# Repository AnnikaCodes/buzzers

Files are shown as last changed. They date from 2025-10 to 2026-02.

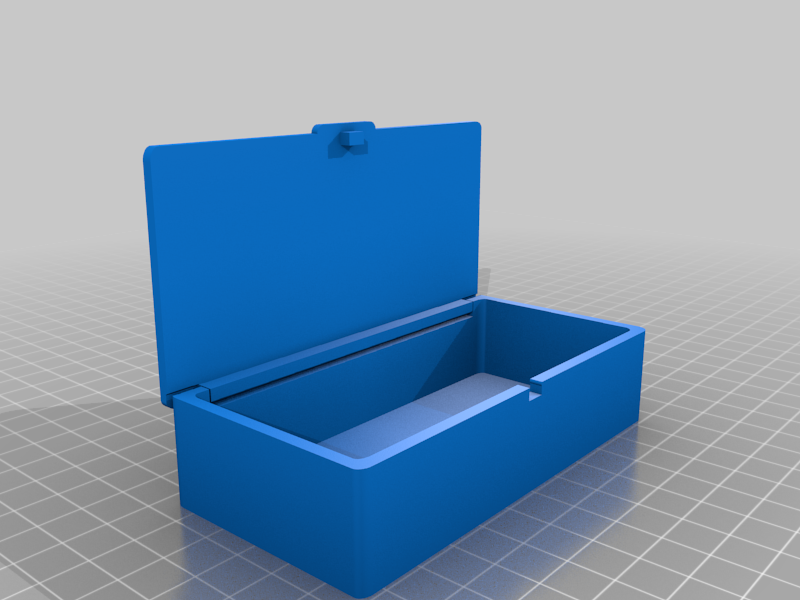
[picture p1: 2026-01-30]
Hinge box with a premounted lid (Print at once) - 1155457/images/e5d918d74d63d429b114cd56e46e2572.png

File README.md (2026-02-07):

# ABACUS: Annika's Buzzers for Ascertaining Competitive Unique Signals
a lower-cost buzzer system for quizbowl competitions

the 3D models were based on https://www.thingiverse.com/thing:12686 and https://www.thingiverse.com/thing:1432052 and https://www.thingiverse.com/thing:1155457

check out [the 'real' website for these!](https://worldbrightening.net/buzzers/)

I don't yet have detailed directions for building it, but you should definitely:
- get a PCB; you can fabricate [these files](https://github.com/AnnikaCodes/buzzers/tree/main/buzzer-pcb), or I'll send you one (almost certainly for cheaper and potentially for free) if you [contact me](mailto:annika@worldbrightening.net)
- buy [stuff from DigiKey](https://www.digikey.com/en/mylists/list/PRWZMR6ARL) (I don't know if this list is complete... you also will definitely need a [speaker](https://www.amazon.com/MakerHawk-Full-Range-Advertising-Connector-Separating/dp/B07GJ4GH67) and some resistors and please, like, [email me about this](mailto:annika@worldbrightening.net) or Discord me or something if you are going to build this! I will help you!)
- print 10 of the [3D models for the buzzers](https://github.com/AnnikaCodes/buzzers/blob/main/3Dmodels/buzzer2.stl) and one of the [3D models for the case](https://github.com/AnnikaCodes/buzzers/blob/main/buzzer-case.stl) (which I still need to move the hole for the cord down to make it actually fit....)
- cut in half your 4p4c cables, push the wire ends through, solder the pushbutton switch to the right wires (this should be RED and GREEN but maybe double check with a multimeter?) and the LED positive lead to black and ground lead to yellow. 
    - be sure to use electrical tape or heatshrink to make it not short itself out!
- glue the buzzers together, and maybe put some superglue around the bottom to stop people from yanking the cord out
- solder all the jacks to the PCB and resistors to limit the current to the LEDs to the board --- whatever you need to reduce 3.3V to a reasonable amount of current given the diode drop of the LED you're using, but I used 50-60 Ohms and mine haven't broken yet.
- solder the Raspberry Pi to the board, maybe with headers if desired
- put red + green LEDs and a switch into the case with wires attached, then attach the wires either directly to the board with solder in the appropriate places, or through headers
- glue the switch into the case, and close the case
- download the software and you're off!

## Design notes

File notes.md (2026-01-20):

# Notes on constructing ABACUS
- Cable scheme: Black - GND (for LED), Red - +3.3V for switch, Green: +2.whateverV for LED, Yellow: switch.
## Notes from the Pi Pico manual
- "If the USB port is the only power source, VSYS and VBUS can be safely shorted together to eliminate the Schottky diode
drop (which improves efficiency and reduces ripple on VSYS)."
   - seems like we should power from USB and short these together
   - could also consider adding batteries, but why?
- Maybe we can use interrupts rather than an active loop --- pg. 16 of https://datasheets.raspberrypi.com/pico/raspberry-pi-pico-python-sdk.pdf --- but I worry about speed.
- I don't think that multicore should help for this project?
- It seems like we can't control USB from MicroPython directly, so we might need to use the REPL for computer-control? Or I2C/SPI/etc?
    - maybe i'm wrong: https://kyuubi0323.github.io/posts/MCU-Pico2/, https://stackoverflow.com/questions/74390514/serial-communication-between-raspberry-pi-pico-and-pc, https://learnembeddedsystems.co.uk/pico-usb-serial-code
    - need to read these ^^^`
- Should probably put resistors before the LEDs, so that voltage across LED is not too high. Want voltage across to be 2.1V at <= 20mA. Say we provide 3.3V initially. Diode drop is ~2.1 V (up to 2.8V), so V drop across resistor is 3.3V - 2.1 V = 1.2V (or at minimum 0.5V). R = V/I = 1.2V/(20 mA) = 60 ohm, so let's try a 60 ohm resistor. 50 ohm would give

- TODO: fix bug where simulatenous buzzes

Buzzer wired 11/8: Green jack wire -> LED +, Red jack wire -> LED -, black & yellow => switch

1/17: to convert proto buzzer -> new buzzer add an extra wire and wire the following in the cable together:
- black->green
- yellow->red
- green->black
- red->yellow

(the PCB jacks send red->input pin, yellow->ground, black->LED resistor, green->3v3

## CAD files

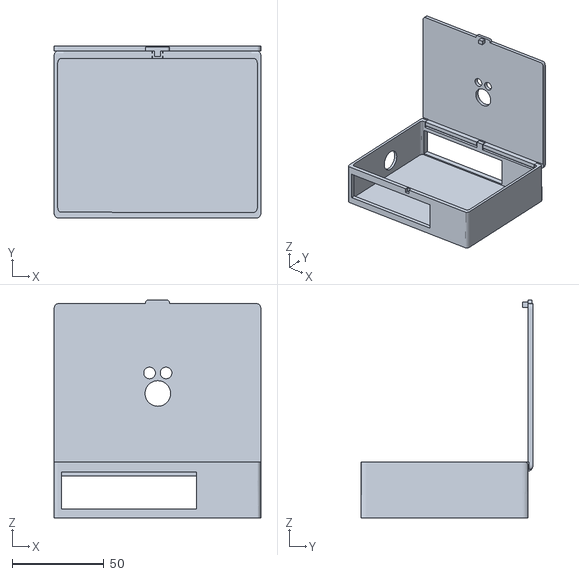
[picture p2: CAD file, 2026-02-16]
3Dmodels/buzzer-case.stl
113.0 x 93.8 x 119.0

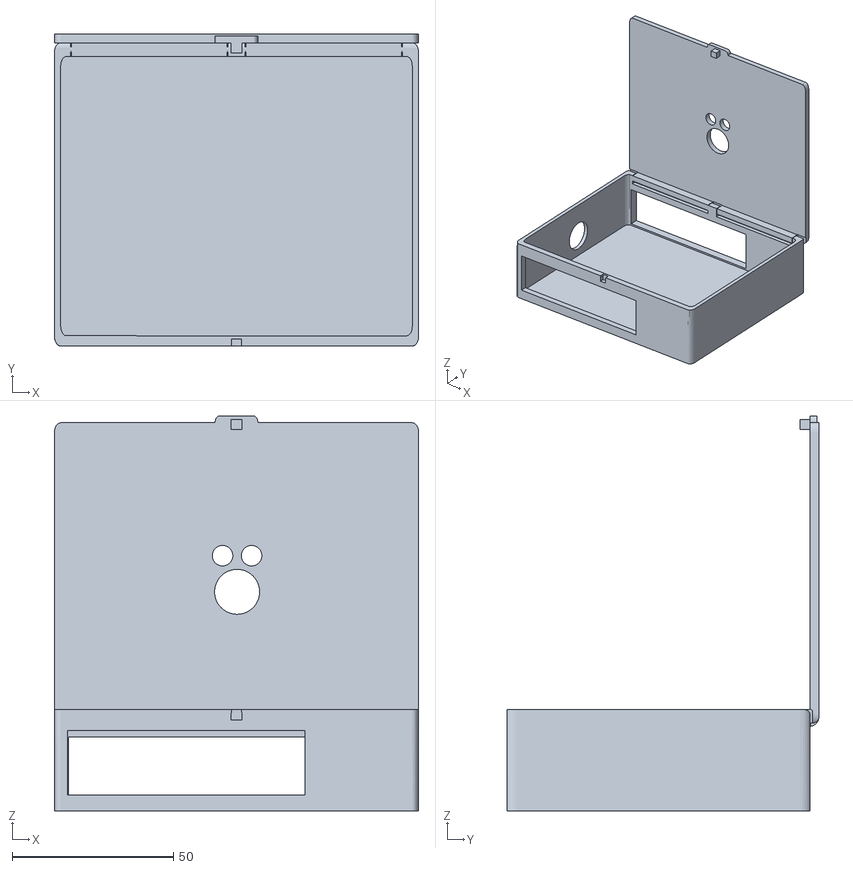
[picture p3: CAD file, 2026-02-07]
buzzer-case.bad.stl
113.0 x 96.8 x 122.5

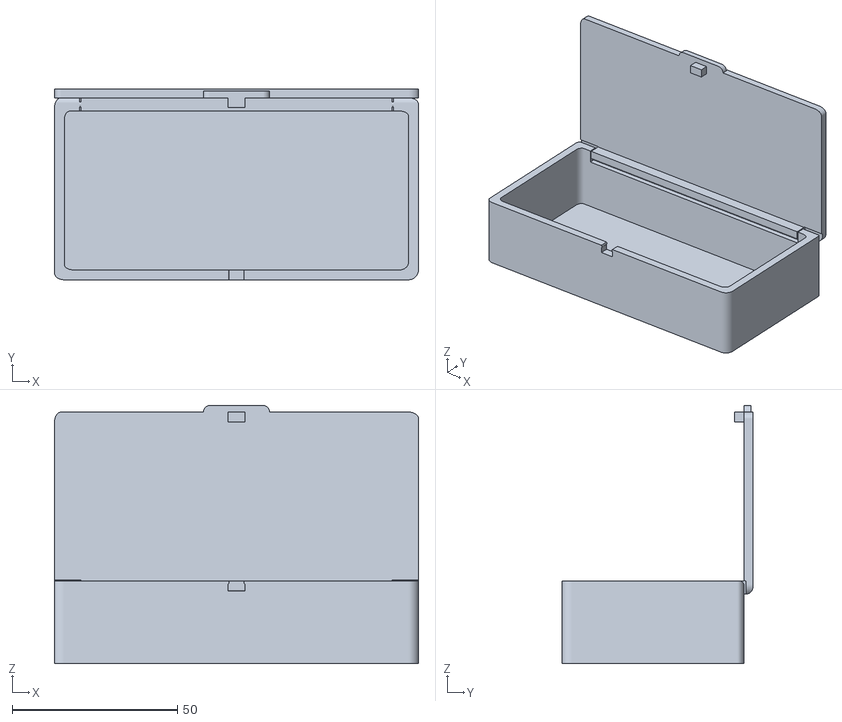
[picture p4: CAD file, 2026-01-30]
Hinge box with a premounted lid (Print at once) - 1155457/files/Hinge_Box-55-110-25.stl
110.0 x 57.6 x 78.0

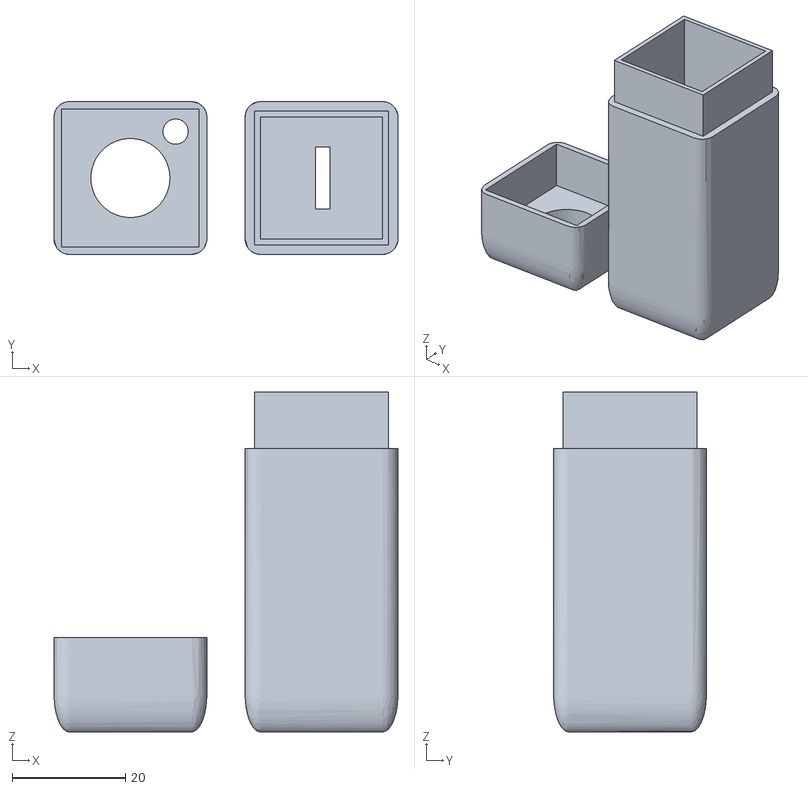
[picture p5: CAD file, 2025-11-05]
3Dmodels/buzzerwiderLEDhole.stl
60.8 x 27.0 x 60.0

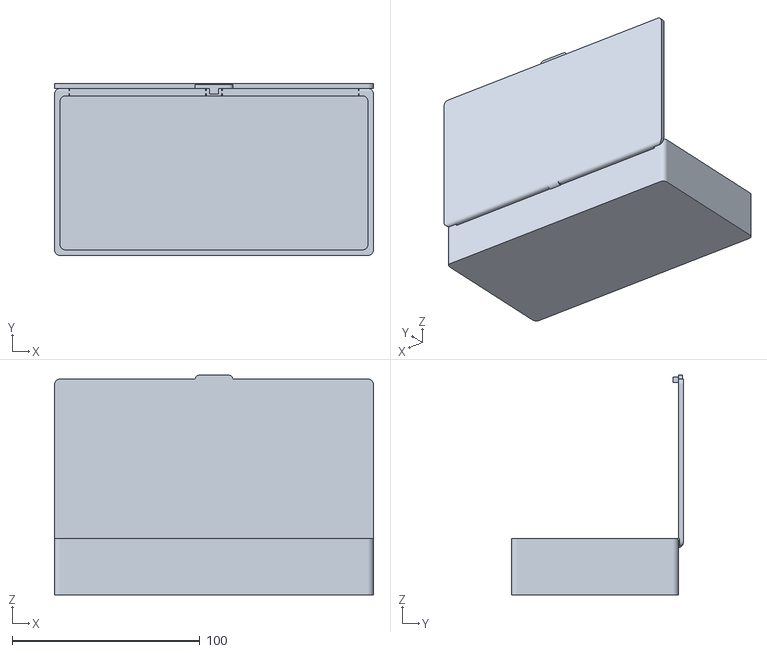
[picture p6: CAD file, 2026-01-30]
Hinge box with a premounted lid (Print at once) - 1155457/files/Hinge_Box-89-170-30.stl
170.0 x 91.6 x 117.0

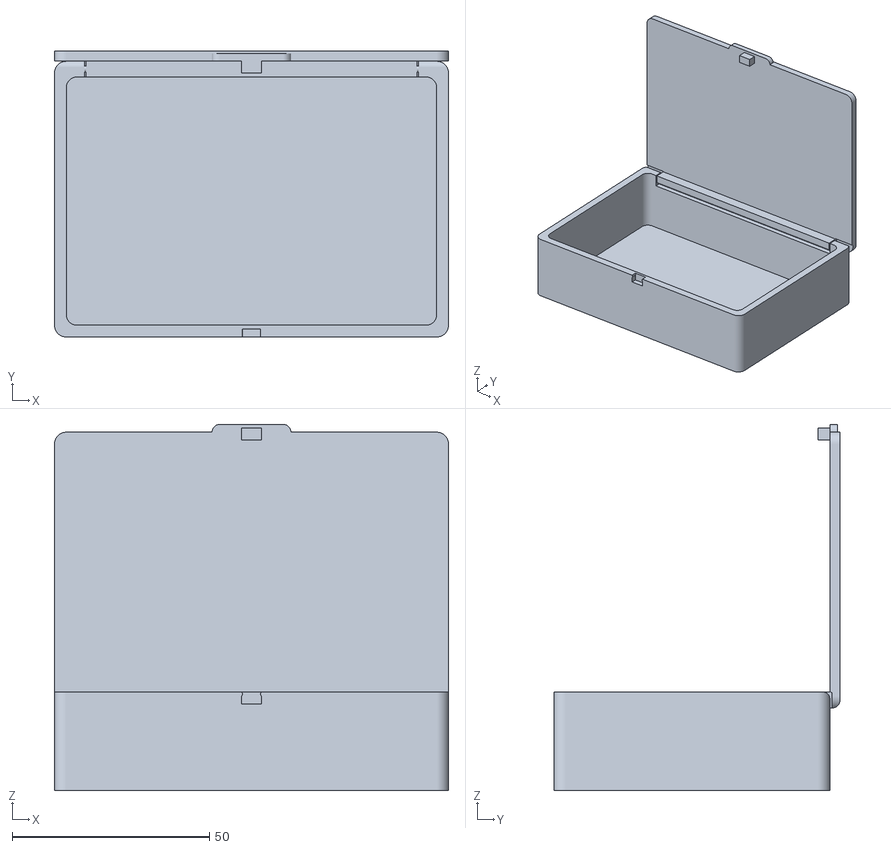
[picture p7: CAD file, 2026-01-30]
Hinge box with a premounted lid (Print at once) - 1155457/files/Hinge_Box-70-100-25.stl
100.0 x 72.6 x 93.0

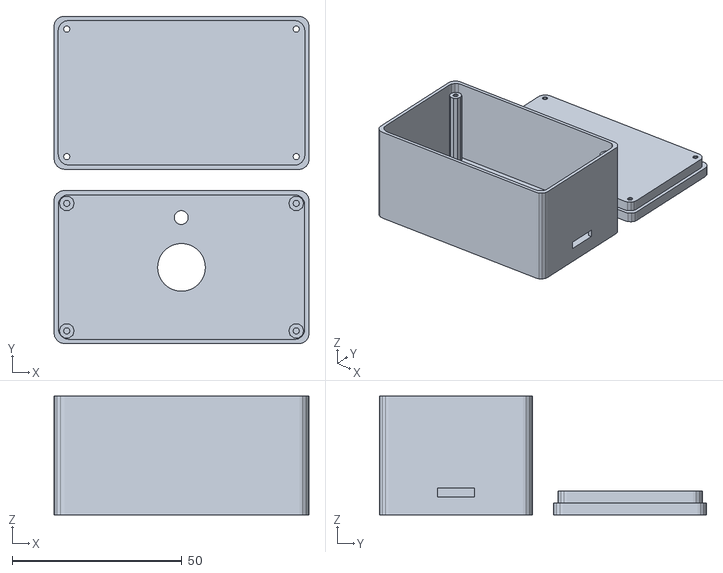
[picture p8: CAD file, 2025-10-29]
3Dmodels/rectangular-buzzer.stl
75.0 x 96.3 x 35.0

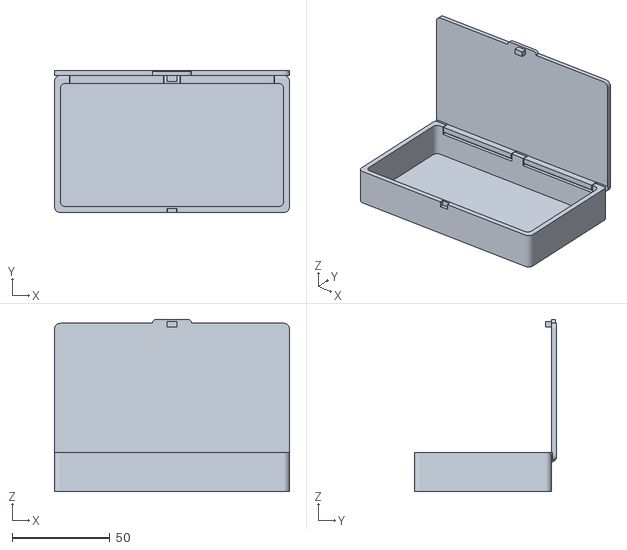
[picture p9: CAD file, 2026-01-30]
Hinge box with a premounted lid (Print at once) - 1155457/files/Hinge_Box-70-120-20.stl
120.0 x 72.6 x 88.0

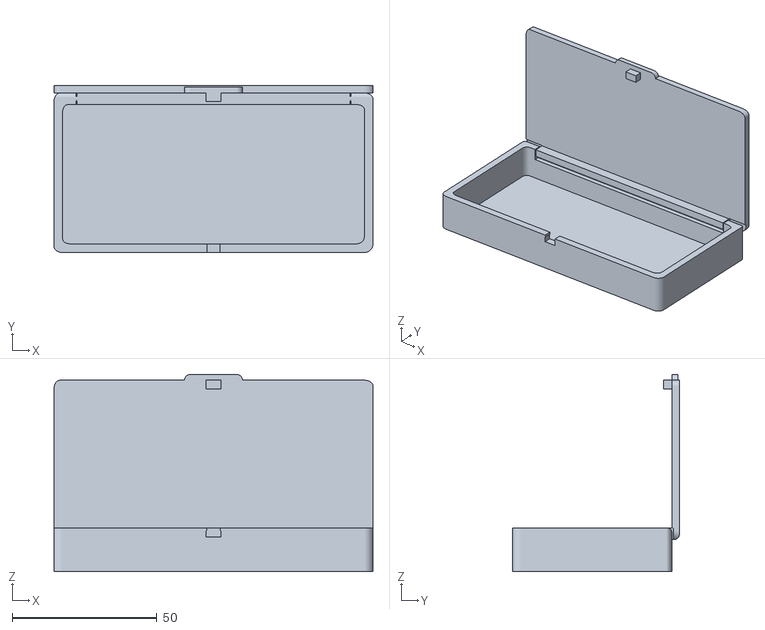
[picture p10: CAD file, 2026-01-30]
Hinge box with a premounted lid (Print at once) - 1155457/files/Hinge_Box-55-110-15.stl
110.0 x 57.6 x 68.0

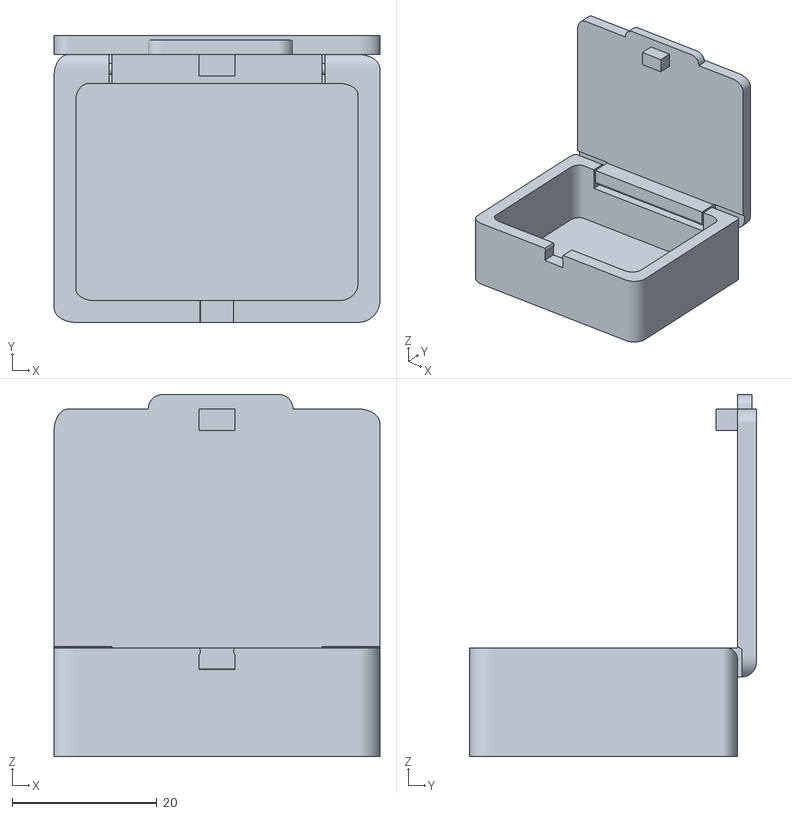
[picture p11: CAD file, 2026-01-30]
Hinge box with a premounted lid (Print at once) - 1155457/files/Hinge_Box-37-45-15.stl
45.0 x 39.6 x 50.0

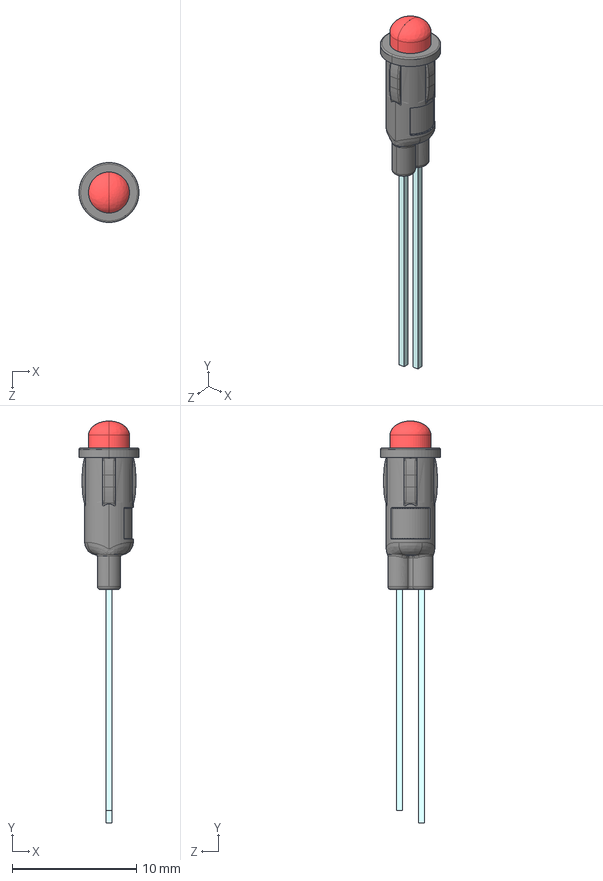
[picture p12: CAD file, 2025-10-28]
3Dmodels/digikey/PM3XXX.igs
4.83 x 32.4 x 4.83 mm

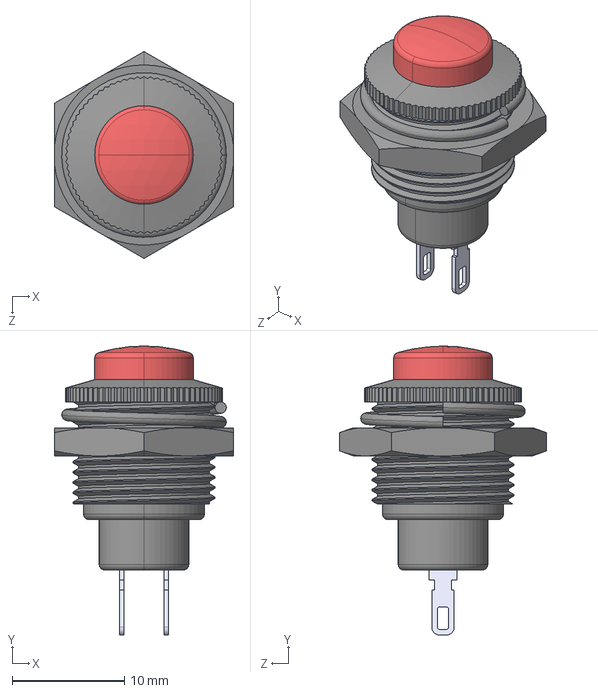
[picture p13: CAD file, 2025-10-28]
3Dmodels/digikey/RP3502ARED.STEP
16.0 x 25.8 x 18.5 mm

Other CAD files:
3Dmodels/buzzer2.stl

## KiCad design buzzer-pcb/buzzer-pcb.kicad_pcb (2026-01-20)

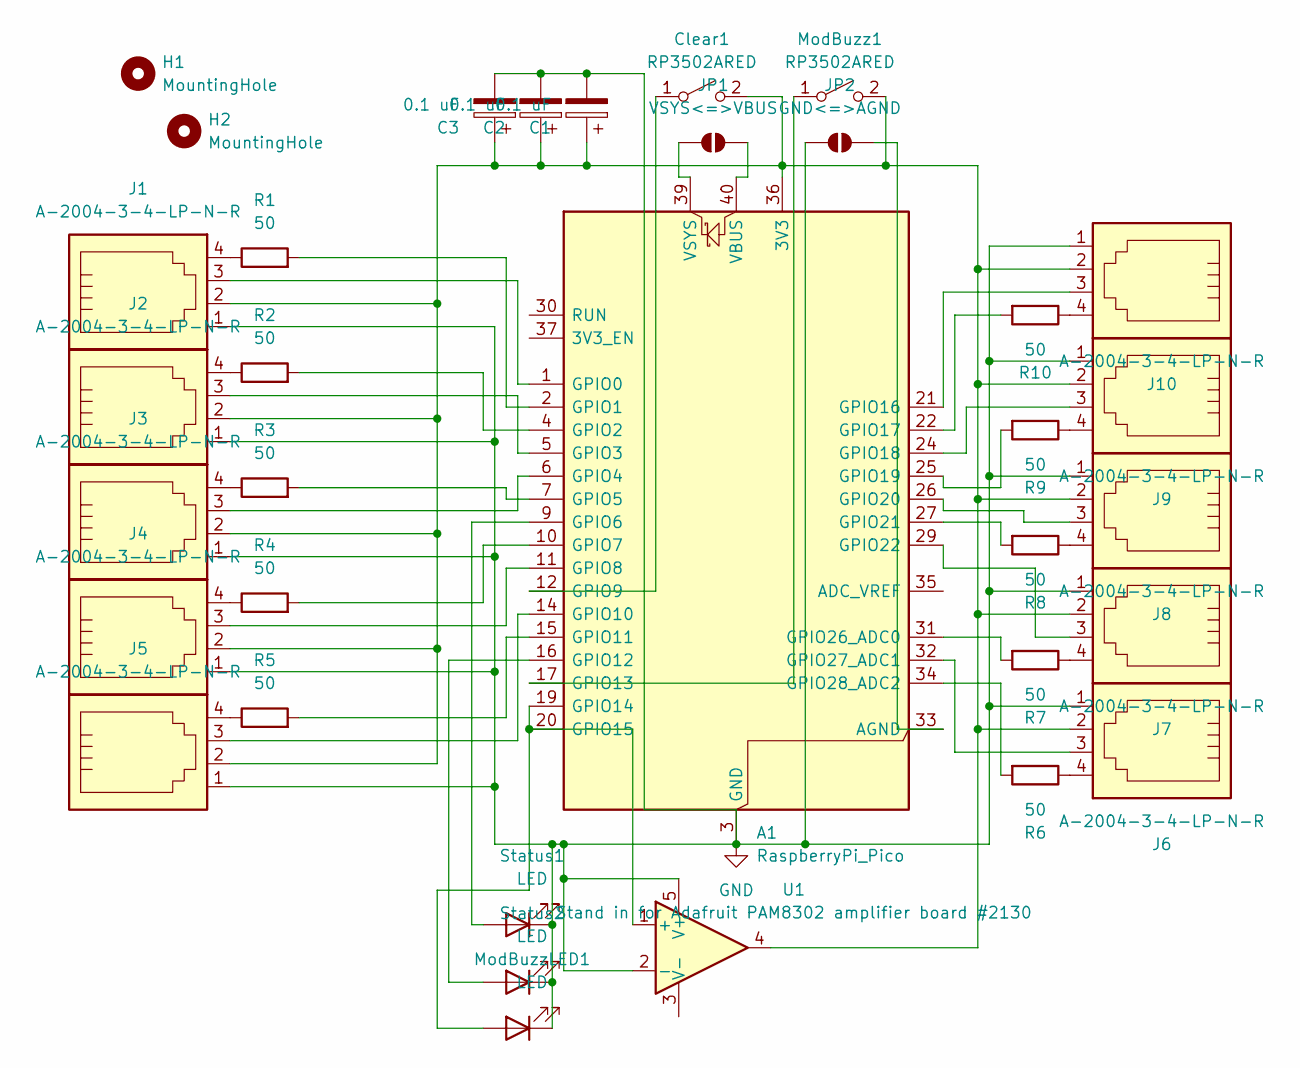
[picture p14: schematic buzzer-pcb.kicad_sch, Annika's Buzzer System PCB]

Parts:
A1: RaspberryPi_Pico; RaspberryPi_Pico_Common_THT
C1, C2, C3: 0.1 uF; XTAL_ZTA-2.44MG
Clear1: RP3502ARED; SW_CW_GPTS203211B
H1, H2: MountingHole; MountingHole_3.2mm_M3
J1, J2, J3, J4, J5, J6, J7, J8, J9, J10: A-2004-3-4-LP-N-R; Jack for Buzzers
JP1: VSYS<=>VBUS; SolderJumper-2_P1.3mm_Bridged_Pad1.0x1.5mm
JP2: GND<=>AGND; SolderJumper-2_P1.3mm_Bridged_Pad1.0x1.5mm
ModBuzz1: RP3502ARED; SW_CW_GPTS203211B
ModBuzzLED1: LED; LED_D5.0mm
R1, R2, R3, R4, R5, R6, R7, R8, R9, R10: 50; R_Axial_DIN0414_L11.9mm_D4.5mm_P15.24mm_Horizontal
Status1, Status2: LED; LED_D5.0mm
U1: Stand in for Adafruit PAM8302 amplifier board #21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; TO-264-5_Horizontal_TabDown

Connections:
GND: A1.3 (GND), A1.8 (GND), A1.13 (GND), A1.18 (GND), A1.23 (GND), A1.28 (GND), A1.38 (GND), C1.2, C2.2, C3.2, J1.1, J2.1, J3.1, J4.1, J5.1, J6.1, J7.1, J8.1, J9.1, J10.1, JP2.1 (A), ModBuzzLED1.1 (K), Status1.1 (K), Status2.1 (K), U1.2 (-), U1.5 (V+)
unnamed: A1.36 (3V3), C1.1, C2.1, C3.1, Clear1.2 (B), J1.2, J2.2, J3.2, J4.2, J5.2, J6.2, J7.2, J8.2, J9.2, J10.2, ModBuzz1.2 (B), U1.4
unnamed: A1.33 (AGND), JP2.2 (B)
unnamed: A1.1 (GPIO0), J1.3
unnamed: A1.2 (GPIO1), R1.2
unnamed: A1.4 (GPIO2), R2.2
unnamed: A1.5 (GPIO3), J2.3
unnamed: A1.6 (GPIO4), J3.3
unnamed: A1.7 (GPIO5), R3.2
unnamed: A1.9 (GPIO6), Status1.2 (A)
unnamed: A1.10 (GPIO7), R4.2
unnamed: A1.11 (GPIO8), J4.3
unnamed: A1.12 (GPIO9), Clear1.1 (A)
unnamed: A1.14 (GPIO10), J5.3
unnamed: A1.15 (GPIO11), R5.2
unnamed: A1.16 (GPIO12), Status2.2 (A)
unnamed: A1.17 (GPIO13), ModBuzz1.1 (A)
unnamed: A1.19 (GPIO14), A1.20 (GPIO15), ModBuzzLED1.2 (A), U1.1 (+)
unnamed: A1.21 (GPIO16), J10.3
unnamed: A1.22 (GPIO17), R10.2
unnamed: A1.24 (GPIO18), J9.3
unnamed: A1.25 (GPIO19), R9.2
unnamed: A1.26 (GPIO20), J8.3
unnamed: A1.27 (GPIO21), R8.2
unnamed: A1.29 (GPIO22), J7.3
unnamed: A1.31 (GPIO26_ADC0), R7.2
unnamed: A1.32 (GPIO27_ADC1), J6.3
unnamed: A1.34 (GPIO28_ADC2), R6.2
unnamed: A1.40 (VBUS), JP1.2 (B)
unnamed: A1.39 (VSYS), JP1.1 (A)
unnamed: J1.4, R1.1
unnamed: J2.4, R2.1
unnamed: J3.4, R3.1
unnamed: J4.4, R4.1
unnamed: J5.4, R5.1
unnamed: J6.4, R6.1
unnamed: J7.4, R7.1
unnamed: J8.4, R8.1
unnamed: J9.4, R9.1
unnamed: J10.4, R10.1

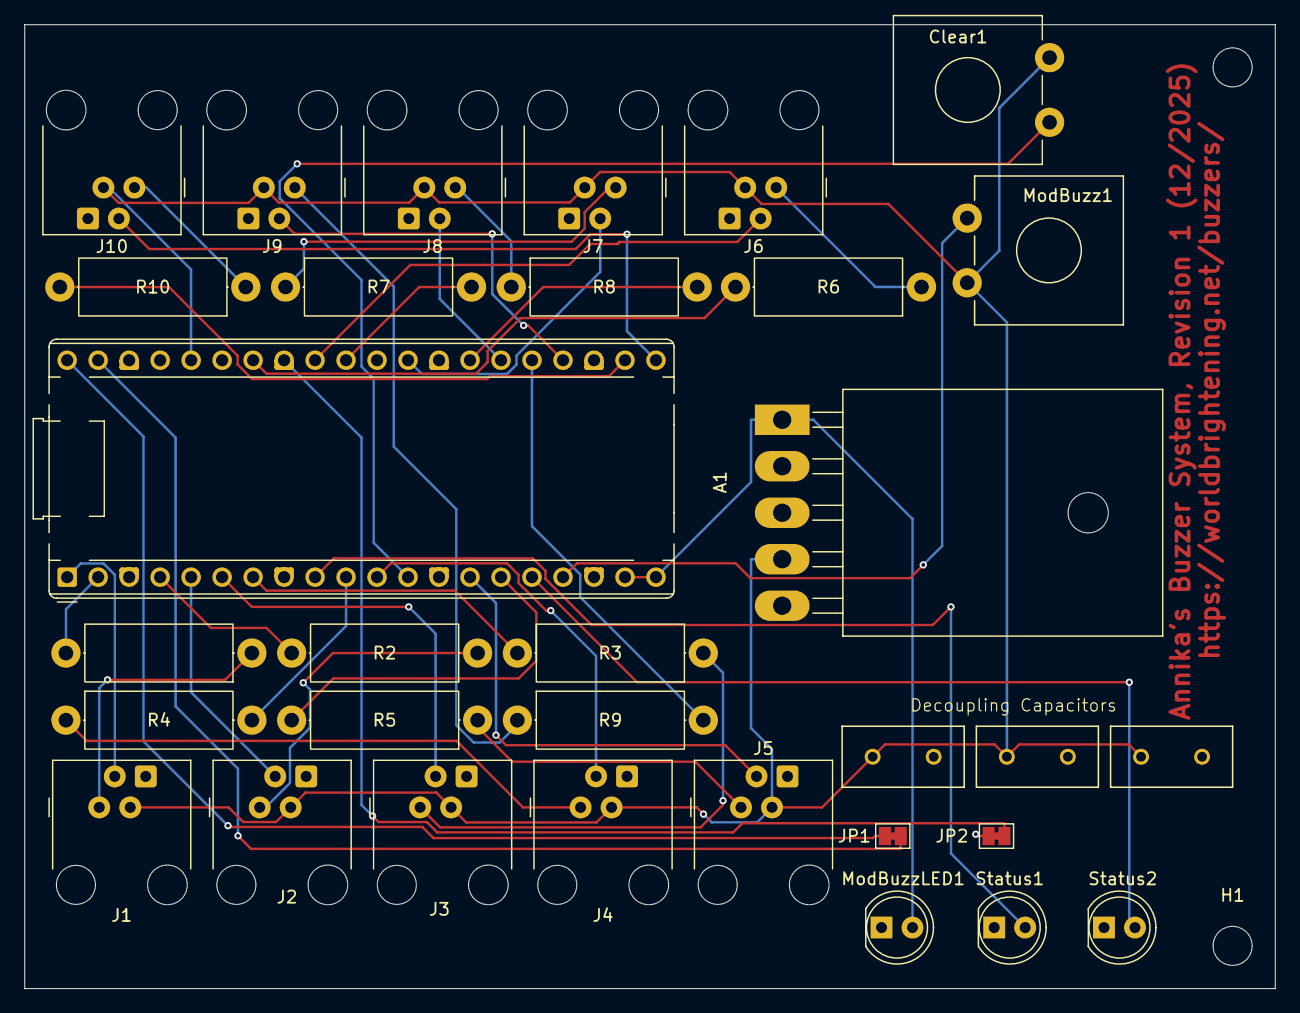
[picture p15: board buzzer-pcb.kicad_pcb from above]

Board: 2 copper layers, 102.5 x 79.0 mm, 34 parts (0 on the bottom side), 40 nets.

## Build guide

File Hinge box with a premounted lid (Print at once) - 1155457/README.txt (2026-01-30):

Hinge box with a premounted lid (Print at once) by AhmetCelikPhd on Thingiverse: https://www.thingiverse.com/thing:1155457

Summary:
Update3 70x120x20 dimension version added.  put extra support for the hinges in this version right in the middle of the lid because it is so tall.Update2 70x100x25 dimension version added.Update1 89x170x30 dimension version added. I put extra support for the hinges in this version right in the middle of the lid because it is so tall.This is a hinged box with a premounted cover.This product is a single piece and its hinge is ready to rotate. No screws, glue, magnet or nails are required.Useful for keeping small stuff like needle, button, secrew, pills or something like these.There is no need to get parts together after print. It designed as a solid piece.You can see that there is opposing covs and rims on both sides over the hinge area.The lid was separate from the box but has to be print at once. It has a opening/closing function due to pre designed hinged part.I've made it completely stable. This is why I deleted previous uploads. If required, I can upload whatever dimesnsions you need.37x45x15Outer dimensions: W: 37mm  L: 45mm  H: 15mmInner dimension: W: 31mm  L: 28mm  H: 12mm55x110x15Outer dimensions: W: 55mm  L: 110mm  H: 15mmInner dimension: W: 49mm  L: 103mm  H: 12mm55x110x25Outer dimensions: W: 55mm  L: 110mm  H: 25mmInner dimension: W: 49mm  L: 103mm  H: 22mm70x100x25Outer dimensions: W: 70mm  L: 100mm  H: 25mmInner dimension: W: 64mm  L: 94mm  H: 22mm70x120x20Outer dimensions: W: 70mm  L: 120mm  H: 20mmInner dimension: W: 64mm  L: 114mm  H: 17mm89x170x30Outer dimensions: W: 89mm  L: 170mm  H: 30mmInner dimension: W: 83mm  L: 164mm  H: 24mmPlease use support. Will not be able to print the hinge properly if you do not use support.

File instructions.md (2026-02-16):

# Detailed notes on how I built the second buzzer set for UCI
1. 3D printed two sets of five buzzers [this gcode file](https://github.com/AnnikaCodes/buzzers/blob/main/3Dmodels/five_buzzers.gcode)
2. Put the jacks ([A-2004-3-4-LP-N-R](https://www.digikey.com/en/products/detail/assmann-wsw-components/A-2004-3-4-LP-N-R/2183632) into the PCB
3. Solder male-male header pins into Raspberry Pi Pico 2.
4. Solder jacks into PCB, 56 Ohm resistor into PCB (R1-R9); R10 got a ~66 Ohm resistor because they're out.
5. For Adafruit STEMMA amp, connect VIN -> 3.3V (4th from top/2nd from bottom where rectangle is at the top), GND -> ground (2nd from the top where the top is the rectangular pin on the audio "A1"), signal -> audio pin (which I think is the rectangle at the top??? but I shall check first)

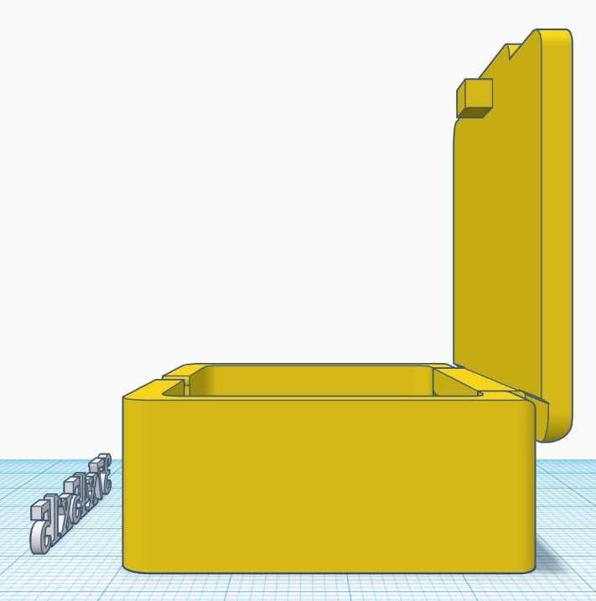
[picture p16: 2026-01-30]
Hinge box with a premounted lid (Print at once) - 1155457/images/yan.jpg

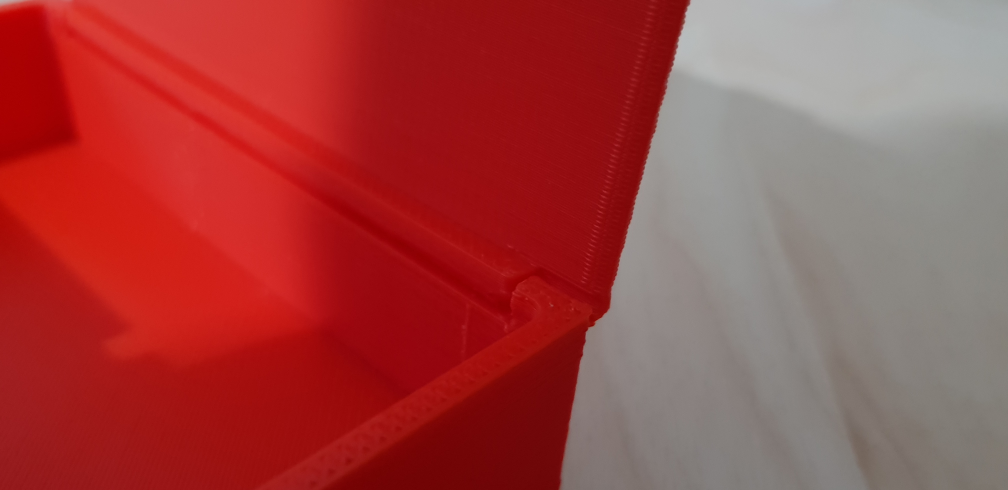
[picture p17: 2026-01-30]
Hinge box with a premounted lid (Print at once) - 1155457/images/image.png

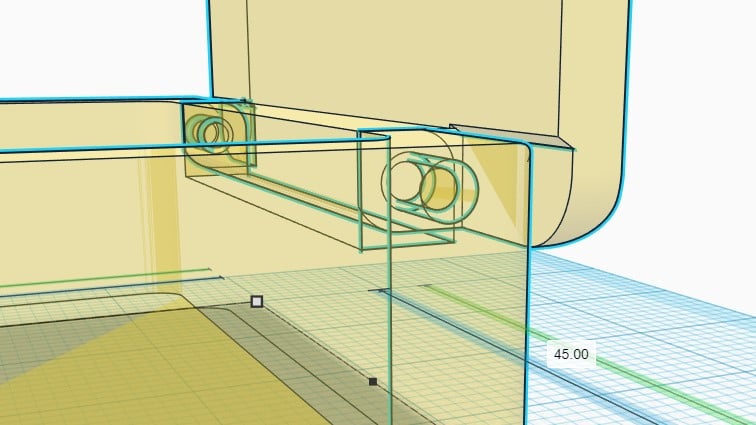
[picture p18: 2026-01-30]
Hinge box with a premounted lid (Print at once) - 1155457/images/mentese.jpg

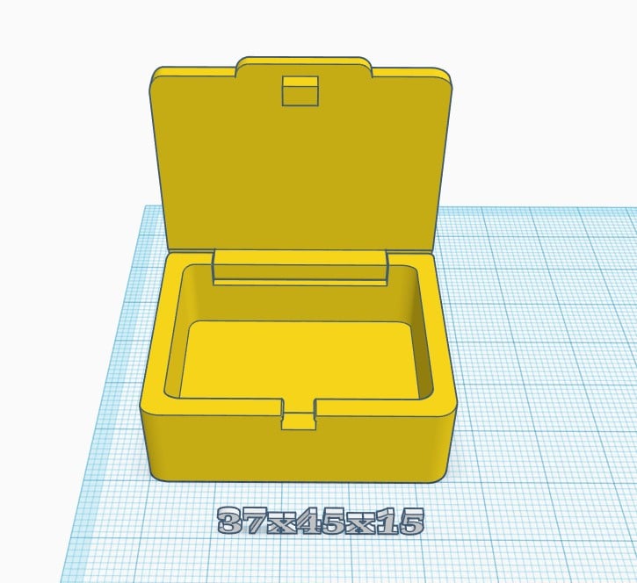
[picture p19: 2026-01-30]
Hinge box with a premounted lid (Print at once) - 1155457/images/37-45-15.jpg

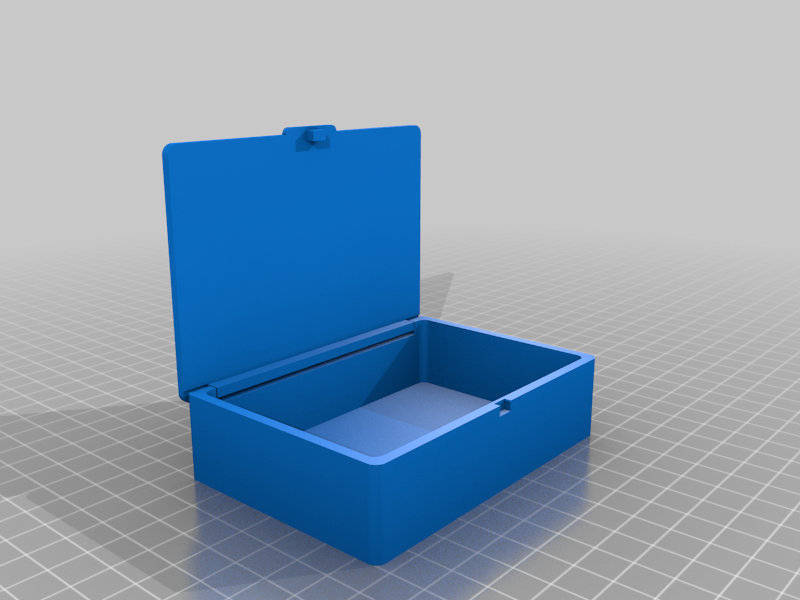
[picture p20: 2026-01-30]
Hinge box with a premounted lid (Print at once) - 1155457/images/Hinge_Box-70-100-25.png

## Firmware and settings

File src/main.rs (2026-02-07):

// Adapted from https://docs.rs/eframe/latest/eframe/
mod app;
mod serial;

fn main() {
    // let mut serial_connection = serial::try_get_serial_connection(1);

    // println!("Reading serial messages...");
    // loop {
    //     match serial::get_serial_message(&mut serial_connection) {
    //         Ok(Some(messages)) => {
    //             for message in messages {
    //                 println!("{}", message.to_human_readable());
    //             }
    //         },
    //         Ok(None) => {
    //             // No message received within timeout
    //         },
    //         Err(e) => {
    //             eprintln!("Error reading serial message: {}", e);
    //         },
    //     }
    // }

    // from https://github.com/emilk/eframe_template/blob/main/src/main.rs#L13
    let native_options = eframe::NativeOptions {
        viewport: egui::ViewportBuilder::default()
            .with_inner_size([400.0, 300.0])
            .with_min_inner_size([300.0, 220.0])
            .with_icon(
                // NOTE: Adding an icon is optional
                eframe::icon_data::from_png_bytes(
                    &include_bytes!("../openclipart-vectors-button-155539.png")[..],
                )
                .expect("Failed to load icon"),
            ),
        ..Default::default()
    };

    match eframe::run_native(
        "Annika's Buzzer System",
        native_options,
        Box::new(|cc| Ok(Box::new(app::App::new(cc)))),
    ) {
        Ok(_) => println!("GUI ran succesfully."),
        Err(e) => {
            eprintln!("Error: {}", e);
            std::process::exit(-1);
        }
    }
}

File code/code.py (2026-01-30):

import digitalio
import board
import audiomp3
import audiopwmio
import protocol

CLEAR_PIN = board.GP13
# (led, switch)
GREEN_TEAM_PINS = [(board.GP17, board.GP16), (board.GP19, board.GP18), (board.GP21, board.GP20), (board.GP26, board.GP22), (board.GP28, board.GP27)] # todo what is pin for last red team?
RED_TEAM_PINS = [(board.GP1, board.GP0), (board.GP2, board.GP3), (board.GP5, board.GP4), (board.GP7, board.GP8), (board.GP11, board.GP10)]

clear = digitalio.DigitalInOut(CLEAR_PIN)
clear.switch_to_input(pull=digitalio.Pull.DOWN)

red_led = digitalio.DigitalInOut(board.GP6)
red_led.switch_to_output(value=False)

green_led = digitalio.DigitalInOut(board.GP12)
green_led.switch_to_output(value=False)

# led, switch, buzz_protocol, lockout_protocol
red_pins = []
green_pins = []
for i in range(len(RED_TEAM_PINS)):
    red_pins.append((
        digitalio.DigitalInOut(RED_TEAM_PINS[i][0]),
        digitalio.DigitalInOut(RED_TEAM_PINS[i][1]),
        protocol.RED_TEAM_BUZZES[i],
        protocol.RED_TEAM_LOCKOUTS[i]
    ))
for i in range(len(GREEN_TEAM_PINS)):
    green_pins.append((
        digitalio.DigitalInOut(GREEN_TEAM_PINS[i][0]),
        digitalio.DigitalInOut(GREEN_TEAM_PINS[i][1]),
        protocol.GREEN_TEAM_BUZZES[i],
        protocol.GREEN_TEAM_LOCKOUTS[i]
    ))
# print(red_pins)

for led, switch, _, _ in red_pins + green_pins:
    led.switch_to_output(value=False)
    led.direction = digitalio.Direction.OUTPUT
    switch.switch_to_input(pull=digitalio.Pull.DOWN)
    led.value = True

import time
red_led.value = True
green_led.value = True
audio = audiopwmio.PWMAudioOut(board.GP14)

def play_startup():
    b = audiomp3.MP3Decoder(open("./startup.mp3", "rb"))
    audio.play(b)
play_startup()
while audio.playing:
    pass
time.sleep(1)

for led, _, _, _ in red_pins + green_pins:
    led.value = False
red_led.value = False
green_led.value = False


# https://learn.adafruit.com/mp3-playback-rp2040/pico-mp3
import supervisor
import sys
def check_for_serial_message():
    if supervisor.runtime.serial_bytes_available:
        return sys.stdin.read(1)
    return ''

def buzzer_loop():
    while True:
        audio.stop()
        led_pin, lockout_exclude = await_buzz(red_pins, green_pins)    
        led_pin.value = True
        t = time.localtime()
        # print(f"buzz! at {t.tm_hour}:{t.tm_min}:{t.tm_sec}")
        play_buzz_tone() # todo: different tones for different teams
        time.sleep(1.5) # delay - not sure why, but sometimes a clear happens right after a buzz
        await_clear(lockout_exclude)
        print(protocol.CLEAR)
        led_pin.value = False
        red_led.value = False
        green_led.value = False

def await_buzz(red, green):
    while True:
        for led, switch, buzz_protocol, lockout_protocol in red + green:
            #print(switch.value)
            if switch.value == True:
                time.sleep(0.01)
                if switch.value == False:
                    continue
                print(buzz_protocol)
                if buzz_protocol >= "F":
                    red_led.value = True
                else:
                    green_led.value = True
                
                return led, lockout_protocol
def await_clear(last_buzz = ''):
    for _ in range(100): # clear buffer
        check_for_serial_message()
    while audio.playing:
        pass
    # duplicated
    locked_out_already = [last_buzz]
    clear.switch_to_output()
    clear.value = False
    clear.switch_to_input(pull=digitalio.Pull.DOWN)
    while clear.value == False:
        m = check_for_serial_message()
        if m == 'x':
            # Forced clear
            return do_clear()
        if m == '2':
            play_two_bits()
        if not audio.playing:
            audio.stop()
        for led, switch, _, lockout_protocol in red_pins + green_pins:
            if switch.value == True and lockout_protocol not in locked_out_already:
                time.sleep(0.1)
                switch.switch_to_output(value=False)
                switch.switch_to_input(pull=digitalio.Pull.DOWN)
                if switch.value != True:
                    continue
                print(lockout_protocol)
                locked_out_already.append(lockout_protocol)
    return do_clear()

def do_clear():
    for led, switch, _, _ in red_pins + green_pins:
        led.value = False
        led.switch_to_output(value=False)
        switch.switch_to_output(value=False)
        switch.value = False
        switch.switch_to_input(pull=digitalio.Pull.DOWN)

    clear.switch_to_output(value=False)
    clear.value = False
    clear.switch_to_input(pull=digitalio.Pull.DOWN)
    return True

def play_buzz_tone():
    buzz_tone = audiomp3.MP3Decoder(open("./buzz.mp3", "rb"))
    audio.play(buzz_tone)

def play_two_bits():
    b = audiomp3.MP3Decoder(open("./two-bits.mp3", "rb"))
    audio.play(b)


buzzer_loop()

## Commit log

2025-10-28 Add 3D model for buzzer
    [PM3XXX.igs, RP3502ARED.STEP, buzzer.stl]
2025-10-29 Buzzer model: Make cable exhaust small
    [buzzer.stl]
2025-10-29 3D model updates
    [buzzer.stl, rectangular-buzzer.stl]
2025-10-29 Add Digikey LED model
    [PM3XXX.igs, RP3502ARED.STEP]
2025-12-28 PCB design
    [buzzer-pcb.kicad_pcb, buzzer-pcb.kicad_sch]
2026-02-16 Update buzzer case model
    [buzzer-case.bad.stl, buzzer-case.stl]
